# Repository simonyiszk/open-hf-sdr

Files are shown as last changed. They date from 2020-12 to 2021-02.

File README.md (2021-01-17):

Open HF SDR
===========

# Specs
* 0.5-30 MHz input freq range

# Receiver
## First stage
* 30 MHz low-pass filter
* Programmable auttenator with 10, 20, and 30 dB options
* Highly linear mixer to 37.224 MHz IF

## Second stage
* IF filter for 37.224 MHz
* IF amplifier
* Mixer to 9 MHz IF

## Third stage
* IF filter for 9 MHz IF with 0.5 MHz bandwidth
* Diff amp to ADC

## Fourth stage
* ADC with 8 MSps, undersampling the 9 MHz IF to 1 MHz

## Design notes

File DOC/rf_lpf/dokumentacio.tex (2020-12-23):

\begin{center}
	\Huge
	30\,MHz vágású aluláteresztő szűrő RH-SDR-hez
	
	\Large
	HA5KFU projekt
	
	\Large
	Keresztes Botond
\end{center}

\section*{Specifikáció}

Cél egy olyan $50\,\Omega$ be-, és kimenetű $30\,MHz$ vágású aluláteresztő szűrő tervezése, mely $44\,MHz$ frekvencián már legalább $40\,dB$-es elnyomást biztosít. Ez azért szükséges, hogy a későbbi keverésből adódó tükörfrekvenciákat megbízhatóan el lehessen nyomni. Továbbá követelmény, hogy a szűrő legfeljebb hetedfokú legyen, ez a főmérnök (Kiss Ádám) által szabott határ.

\section*{Első iteráció}

A szűrő méretezéséhez az \url{https://rf-tools.com/lc-filter/} linken található programot használtam, itt specifikálni lehet a szűrő típusát (Csebisev, Butterworth stb.), jellegét (alul-, felüláteresztő stb.), vágási frekvenciá(ka)t, illetve ahol releváns, egyéb paramétereket (pl. áteresztő sávi hullámosság). Ezen kívül kiszámíttathatók az elemek pontos értékei, vagy a szabványos sorokban található értékekből felépített közelítése.

Az első próbálkozás (\ref{fig:csebisev_390n}-es ábra) egy hetedfokú Csebisev szűrő volt, ugyanis ez ígérkezett megfelelő meredekséget adni a határok megtartásához. Ezt teljesítette is, bár csak úgy, ha $0,3\,dB$-nyi hullámosságot engedélyeztem a zárósávban. Ez a struktúra két különböző kondenzátor, illetve induktivitás értéket ($360\,nH$, $390\,nH$) tartalmazott. A számok relatív közelsége miatt adta magát, hogy áttérjek egyfajta tekercsértékre (\ref{fig:csebisev_360n}-es ábra), így csökkentve a különböző alkatrészek mennyiségét.

Az \texttt{rf-tools} tervezőben sajnos nincs lehetőség egyes értékek manuális átírására, így a további szimulációkat LTSpice-ban végeztem\footnotemark. Ennek az az előnye, hogy exportálhatók a szimulációs eredmények. Ezzel a lehetőséggel éltem is, és Octave segítségével ábrázoltam az eredményeket (lásd: Függelék).
\footnotetext{A forrás és terhelés ellenállás osztása miatt itt a kimenet alapból $-6\,dB$ csillapítással számítódik, ezt az ábrázolásnál ki kell (lehet) kompenzálni.}

Az tekercsek egységes $360\,nH$-re cserélése ugyan kicsit kijjebb tolja a $-3\,dB$-es pontot, viszont növeli az áteresztő sávi hullámosságot, és csökkenti az elnyomás mértékét $44\,MHz$-en. Mérlegelendő, hogy az alkatrészek számán szeretnénk-e spórolni, vagy inkább egy jobb karakterisztikájú szűrőre van szükségünk.

Erre a diskurzusra viszont sor sem kerülhetett, ugyanis ezen szűrők úgy lettek méretezve, hogy az \texttt{rf-tools} az E24-es sorban található szabványos értékeket használta fel a tervezéshez, viszont hamar kiderült, hogy ezen alkatrészek elérhetősége (névelegesen a $360\,nH$-s tekercsé) igencsak csekély.

\newpage

\section*{Második iteráció}

Világossá vált, hogy ha bármiféle választékot szeretnénk az alkatrészek beszerzésekor, akkor át kell térni E12-es értéksorra. Ebben természetesen \enquote{szellősebben} találhatók elemértékek, viszont az elérhetőségük jóval jobb.

Ádámmal konzultálva arra jutottunk, hogy a prioritás a $44\,MHz$-es elnyomási kritérium teljesítése, és hogy ez akár kierőszakolható a törésponti frekvenciának a csökkentésével. A határértékekkel való kis játék után adódott, hogy a sávszélesség $29,5\,MHz$-re választásával elérhető a specifikált elnyomás, mindössze $0,2\,dB$ hullámossággal -- az \texttt{rf-tools} ez számította, a szimuláció (\ref{fig:csebisev_295}-as ábra) ezzel nem teljesen egyezett.

Ez egy észszerű kompromisszumnak mutatkozik az eredeti követelmények és az alkatrész elérhetőség között, így ezt a változatot szándékozzuk használni.

\section*{Alkatrészek}

Alkatrészek keresésekor fő szempont volt az ár és az elérhetőség és természetesen a minőség. Ez a tekercs esetén magas rezonanciafrekvenciát és alacsony ellenállást jelent, kondenzátoroknál pedig igyekeztem olyan márkából is beválogatni egyet-egyet, melyekről mondták nekem, hogy azok jó minőségűek nagyobb frekvenciákon is. Jelenleg úgy alakult, hogy ez minden esetben a Kemet, de ilyen még pl. a Vishay vagy a Murata is.

Kiválasztásra került több lehetséges érték, ha esetleg gondok merülnének fel a rendeléssel (értsd: elfogy a raktárkészlet), illetve a kondenzátoroknál két különböző méretből is listáztam terméket, ugyanis itt nem elhanyagolható az árbeli különbség. Az általam javasolt alkatrészek minden táblázatban és a hivatkozások között is vastagon ki vannak emelve, de alkalmazásuk akár vita tárgyát képezheti.

\subsection*{Tekercs}

\begin{center}
	\begin{tabular}{ c c c c c c c c }
		\textbf{Forgalmazó} & \textbf{Gyártó} & \textbf{Érték} & \textbf{Méret} & \textbf{Ellenállás} & \textbf{SRF} & \textbf{Ár [db]} & \textbf{Link}\\
		
		\hline \\
		
		\textbf{Farnell} & \textbf{TDK} & \textbf{390\,nH} & \textbf{1210} & \textbf{0,45\,$\Omega$} & \textbf{250\,MHz} & \textbf{kb. 60\,Ft} & \textbf{\cite{tdk_tekercs}} \\[10pt]
		
		Farnell & WE & 390\,nH & 0603 & 2,3\,$\Omega$ & 350\,MHz & kb. 30\,Ft & \cite{we_tekercs} \\[10pt]
		
		Lomex & KOA & 390\,nH & 1210 & 0,45\,$\Omega$ & 250\,MHz & kb. 45\,Ft & \cite{koa_tekercs}

	 	\end{tabular}
\end{center}

\subsection*{Kondenzátor}

\begin{center}
	\begin{tabular}{ c c c c c c c c }
		\textbf{Forgalmazó} & \textbf{Gyártó} & \textbf{Érték} & \textbf{Méret} & \textbf{Tűrés} & \textbf{Egyéb} & \textbf{Ár [db]} & \textbf{Link}\\
		
		\hline \\
		
		\textbf{Farnell} & \textbf{Kemet} & \textbf{150\,pF} & \textbf{0805} & \textbf{5\%} & \textbf{NP0} & k\textbf{b. 20\,Ft} & \textbf{\cite{kemet_150p_0805}} \\[10pt]
		
		Farnell & WE & 150\,pF & 0805 & 10\% & X7R & kb. 20\,Ft & \cite{we_150p_0805} \\[10pt]
		
		Farnell & Walsin & 150\,pF & 0603 & 5\% & NP0 & kb. 6\,Ft & \cite{walsin_150p_0603} \\[10pt]
		
		Farnell & Kemet & 150\,pF & 0603 & 5\% & NP0 & kb. 9\,Ft & \cite{kemet_150p_0603} \\[10pt]
		
		\hline \\
		
		\textbf{Farnell} & \textbf{Kemet} & \textbf{270\,pF} & \textbf{0805} & \textbf{5\%} & \textbf{NP0} & \textbf{kb. 21\,Ft} & \textbf{\cite{kemet_270p_0805}} \\[10pt]
		
		Farnell & Multicomp & 270\,pF & 0805 & 5\% & NP0 & kb. 23\,Ft & \cite{multicomp_270p_0805} \\[10pt]
		
		Farnell & Walsin & 270\,pF & 0603 & 10\% & X7R & kb. 7\,Ft & \cite{walsin_270p_0603} \\[10pt]
		
		Farnell & Kemet & 270\,pF & 0603 & 5\% & NP0 & kb. 15\,Ft & \cite{kemet_270p_0603} \\[10pt]
		
	\end{tabular}
\end{center}

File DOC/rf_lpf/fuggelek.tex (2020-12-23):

\section*{Függelék}
\label{sec:fuggelek}

\begin{thebibliography}{1}
	
	\bibitem{tdk_tekercs} \textbf{TDK tekercs 390\,nH} \url{https://hu.farnell.com/tdk/nlv32t-r39j-ef/inductor-0-39uh-0-45a-1210/dp/2747947}
	
	\bibitem{we_tekercs} Würth Elektronik tekercs 390\,nH \url{https://hu.farnell.com/wurth-elektronik/7447860239/inductor-390nh-350mhz-0-15a-0603/dp/3518544RL}
	
	\bibitem{koa_tekercs} KOA tekercs 390\,nH \url{https://lomex.hu/hu/webshop/#/search,93-00-46/stype,1}
	
	\bibitem{kemet_150p_0805} \textbf{Kemet kondenzátor 150\,pF, 0805} \url{https://hu.farnell.com/kemet/c0805c151j5gacauto/cap-150pf-50v-5-c0g-np0-0805/dp/2905219}
	
	\bibitem{we_150p_0805} Würth Elektronik kondenzátor 150\,pF, 0805 \url{https://hu.farnell.com/wurth-elektronik/885012207055/cap-150pf-25v-10-x7r-0805/dp/2812410}
	
	\bibitem{walsin_150p_0603} Walsin kondenzátor 150\,pF, 0603 \url{https://hu.farnell.com/walsin/0603n151j500ct/cap-150pf-50v-5-c0g-np0-0603/dp/2496888}
	
	\bibitem{kemet_150p_0603} Kemet kondenzátor 150\,pF, 0603 \url{https://hu.farnell.com/kemet/c0603c151j5gactu/cap-150pf-50v-5-c0g-np0-0603/dp/1414615}
	
	\bibitem{kemet_270p_0805} \textbf{Kemet kondenzátor 270\,pF, 0805} \url{https://hu.farnell.com/kemet/c0805c271j5gactu/cap-270pf-50v-5-c0g-np0-0805/dp/1414684}
	
	\bibitem{multicomp_270p_0805} Multicomp Pro kondenzátor 270\,pF, 0805 \url{https://hu.farnell.com/multicomp/mc0805n271j500ct/cap-270pf-50v-5-c0g-np0-0805/dp/1759211}
	
	\bibitem{walsin_270p_0603} Walsin kondenzátor 270\,pF, 0603 \url{https://hu.farnell.com/walsin/0603b271k500ct/cap-270pf-50v-10-x7r-0603-reel/dp/2524832}
	
	\bibitem{kemet_270p_0603} Kemet kondenzátor 270\,pF, 0603 \url{https://hu.farnell.com/kemet/c0603c271j5gactu/cap-270pf-50v-5-c0g-np0-0603/dp/1414629}

\end{thebibliography}

\newpage

\subsection*{7-ed fokú Csebisev szűrő, 390nH induktivitással (E24-es sor)}

\begin{figure}[!ht]
	\centering
	\begin{subfigure}[b]{\textwidth}
		\centering
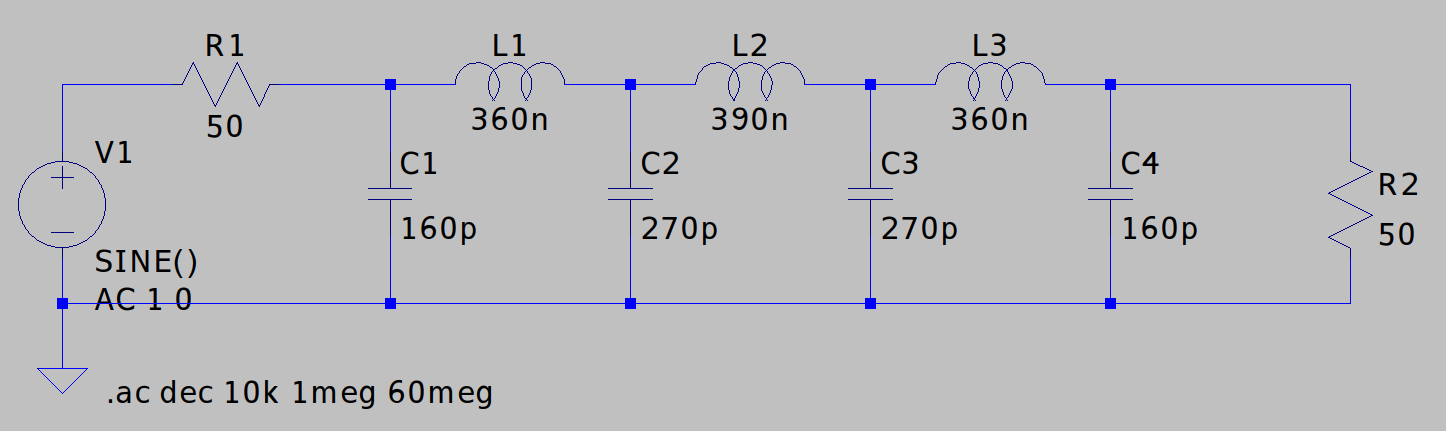
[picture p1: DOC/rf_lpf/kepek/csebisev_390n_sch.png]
		\centerline{[}
		\label{fig:csebisev_390n_sch}
		\caption{Struktúra}
	\end{subfigure}
	\hfill
	\begin{subfigure}[b]{\textwidth}
		\centering
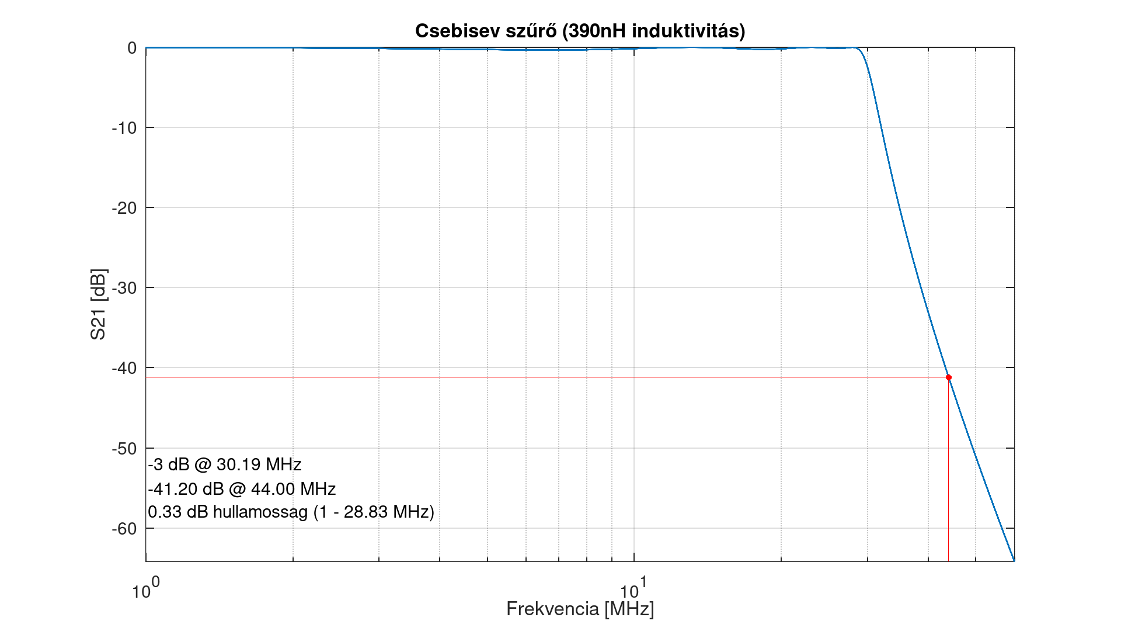
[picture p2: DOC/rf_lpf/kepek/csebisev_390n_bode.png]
		\centerline{[}
		\label{fig:csebisev_390n_bode}
		\caption{Frekvenciamenet}
	\end{subfigure}
	\caption{7-ed fokú Csebisev szűrő, 390nH induktivitással (E24-es sor)}
	\label{fig:csebisev_390n}
\end{figure}

\newpage

\subsection*{7-ed fokú Csebisev szűrő, kizárólag 360nH induktivitásokkal (E24-es sor)}

\begin{figure}[!ht]
	\centering
	\begin{subfigure}[b]{\textwidth}
		\centering
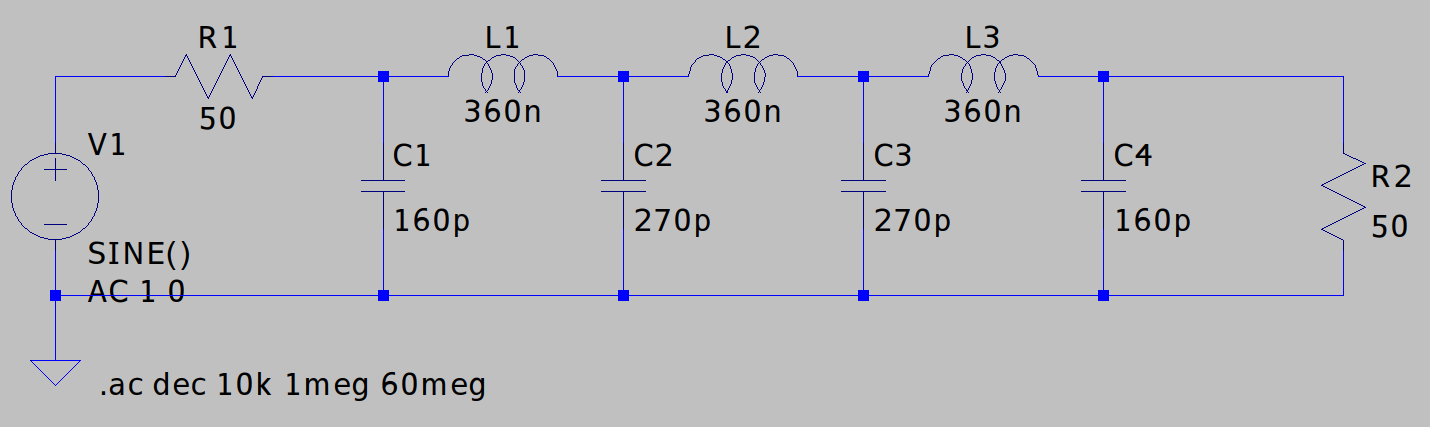
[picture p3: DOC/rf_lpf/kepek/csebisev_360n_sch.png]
		\centerline{[}
		\label{fig:csebisev_360n_sch}
		\caption{Struktúra}
	\end{subfigure}
	\hfill
	\begin{subfigure}[b]{\textwidth}
		\centering
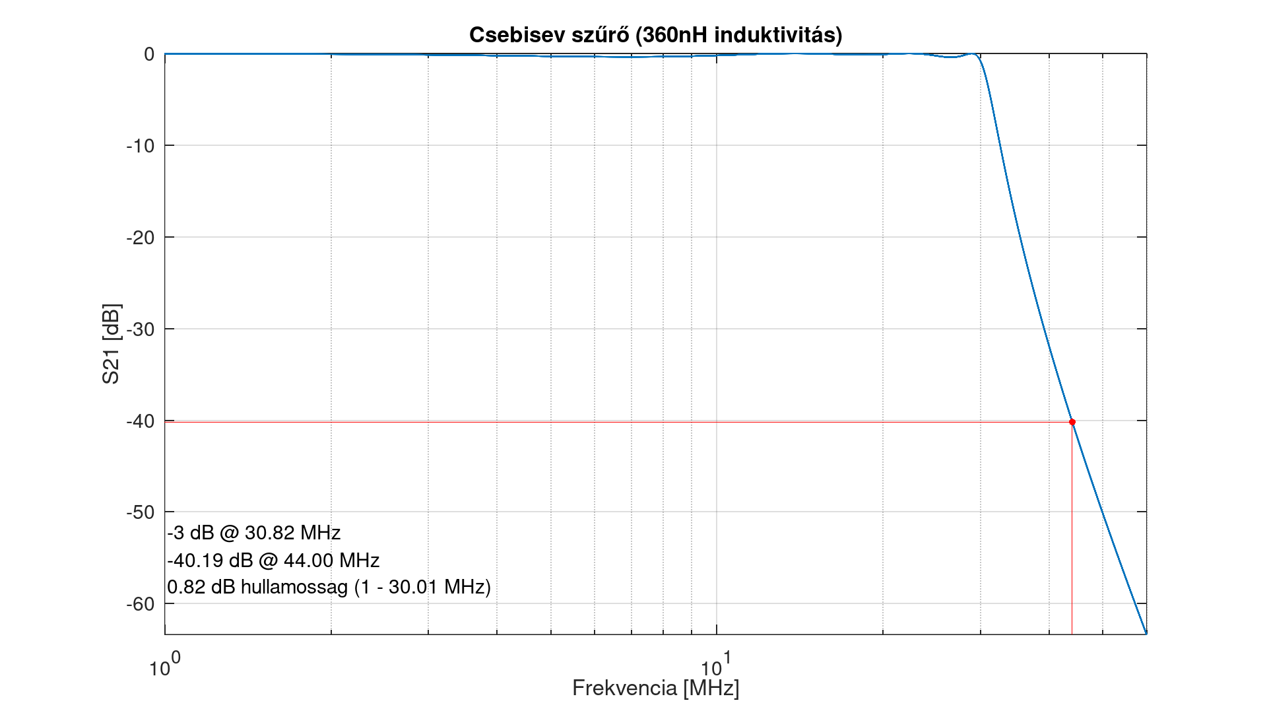
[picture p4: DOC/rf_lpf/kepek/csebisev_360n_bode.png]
		\centerline{[}
		\label{fig:csebisev_360n_bode}
		\caption{Frekvenciamenet}
	\end{subfigure}
	\caption{7-ed fokú Csebisev szűrő, kizárólag 360nH induktivitásokkal (E24-es sor)}
	\label{fig:csebisev_360n}
\end{figure}

\newpage

\subsection*{7-ed fokú Csebisev szűrő, 29,5\,MHz vágással és E12-es sorelemekkel}

\begin{figure}[!ht]
	\centering
	\begin{subfigure}[b]{\textwidth}
		\centering
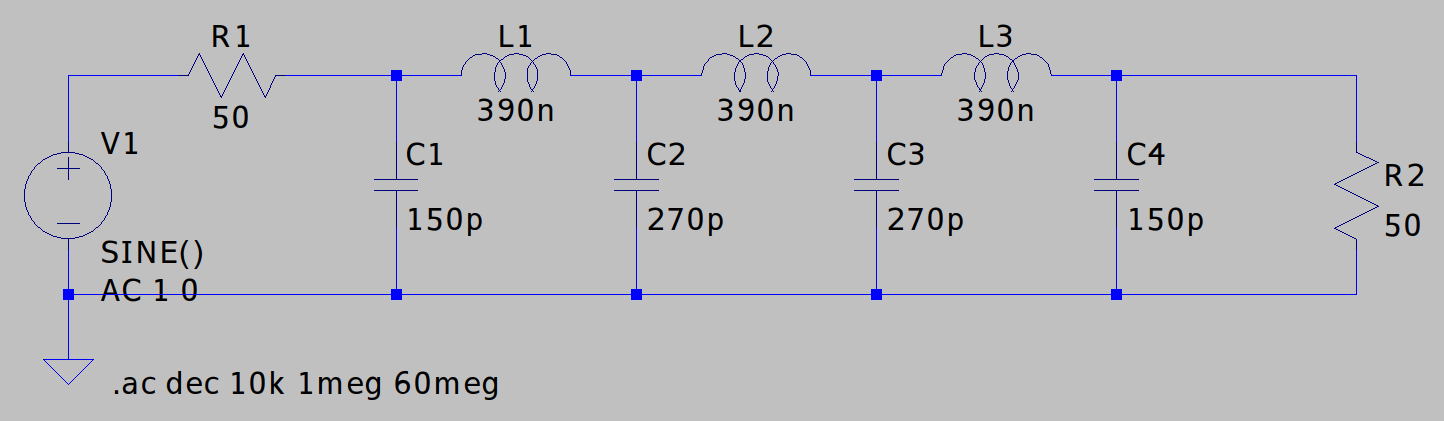
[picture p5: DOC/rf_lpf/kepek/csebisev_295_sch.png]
		\centerline{[}
		\label{fig:csebisev_295_sch}
		\caption{Struktúra}
	\end{subfigure}
	\hfill
	\begin{subfigure}[b]{\textwidth}
		\centering
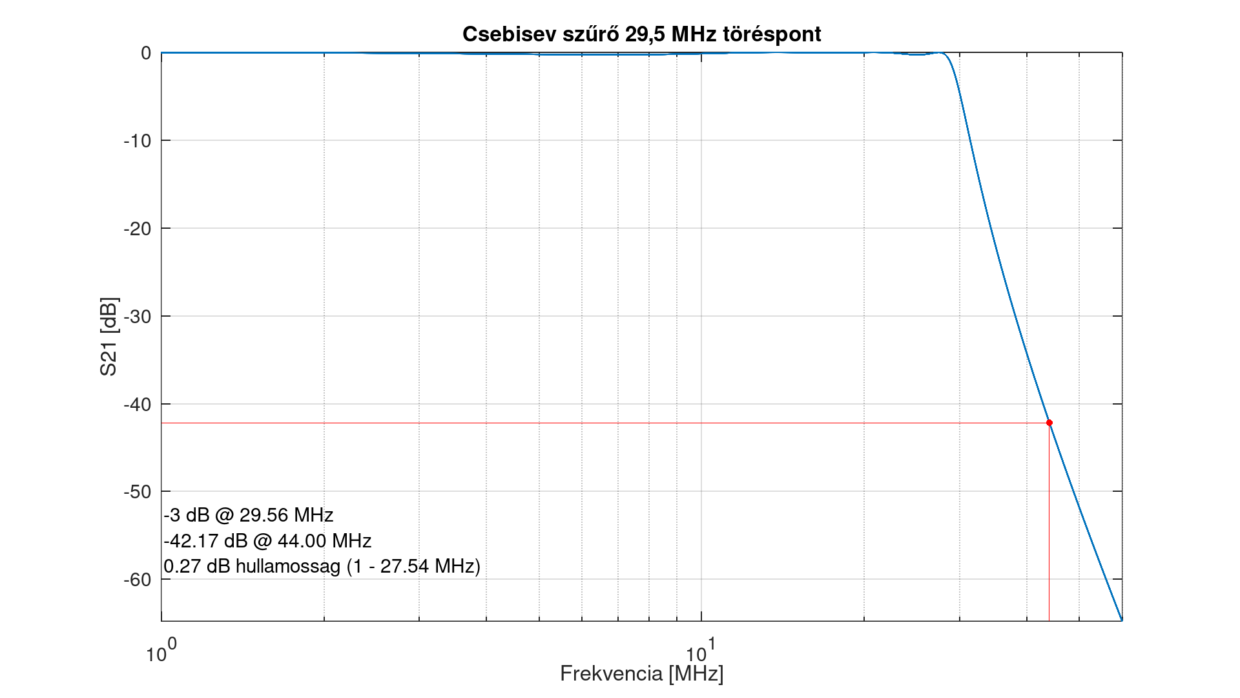
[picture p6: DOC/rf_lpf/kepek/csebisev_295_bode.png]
		\centerline{[}
		\label{fig:csebisev_295_bode}
		\caption{Frekvenciamenet}
	\end{subfigure}
	\caption{7-ed fokú Csebisev szűrő, 29,5\,MHz vágással és E12-es sorelemekkel}
	\label{fig:csebisev_295}
\end{figure}

\newpage

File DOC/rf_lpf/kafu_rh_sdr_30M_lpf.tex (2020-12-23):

\documentclass[12pt,a4paper,oneside]{article}
\usepackage{geometry}
	\geometry                  %margók és lapméret beállítása
		{
			a4paper,
			top=20mm,
			bottom=25mm,
			left=25mm,
			right=25mm
		}
	\pagestyle{plain}           %fejléc üres, lábléc az oldalszámot tartalmazza
\usepackage{setspace}           %sorközt lehet beállítani
	\singlespacing              %egyszeres sorköz
\usepackage{indentfirst}        %bekezdések formázása
	\setlength{\parindent}{1em} %bekezdés első sorának behúzása
	\setlength{\parskip}{6pt}   %bekezdések közötti távolság
\usepackage[autostyle]{csquotes}%idézőjelek helyes formázásához
	
\usepackage[utf8]{inputenc}     %karakterkódolás
\usepackage[magyar]{babel}      %helyesírás-ellenőrzés
\usepackage[T1]{fontenc}        %szimbólumkódolás

\usepackage{amsmath}            %matematikai képletekhez
\usepackage{amssymb}            %több matematikai jelölés (automatikusan betölti az 'amsfonts' csomagot)
\usepackage{graphicx}           %képek beillesztéséhez (valószínűleg betölti a 'graphics' csomagot, de nem találtam erre egyértelmű hivatkozást)
	\graphicspath               %képek elérési útvonala, szabadon bővíthető/csökkenthető
	{
		{./}
		{./elolap/}
		{./kepek/}
	}
\usepackage{enumitem}           %felsorolásokat lehet vele formázni
\usepackage{titling}            %title, author, stb. definiálásához, használatához
\usepackage{hyperref}           %a hivatkozásokat kezeli
	\hypersetup                 %a hivatkozásokat lehet formálni
	{
		colorlinks=true,        %linkek színezésének engedélyezése
		citecolor=black,        %dokumentumon belüli hivatkozás színe
		linkcolor=red,          %valami másféle dokumentumon belüli hivatkozás színe
		urlcolor=blue,          %weblaphivatkozások színe
	}
\usepackage[center]{caption}    %képaláírásokat alapból középre igazítja
\usepackage{subcaption}         %subfigure környezethez
\usepackage{float}              %'lebegő' objektumok (pl. képek, táblázatok) pozícionálására

\begin{document}
	\include{dokumentacio}
	\include{fuggelek}
\end{document}

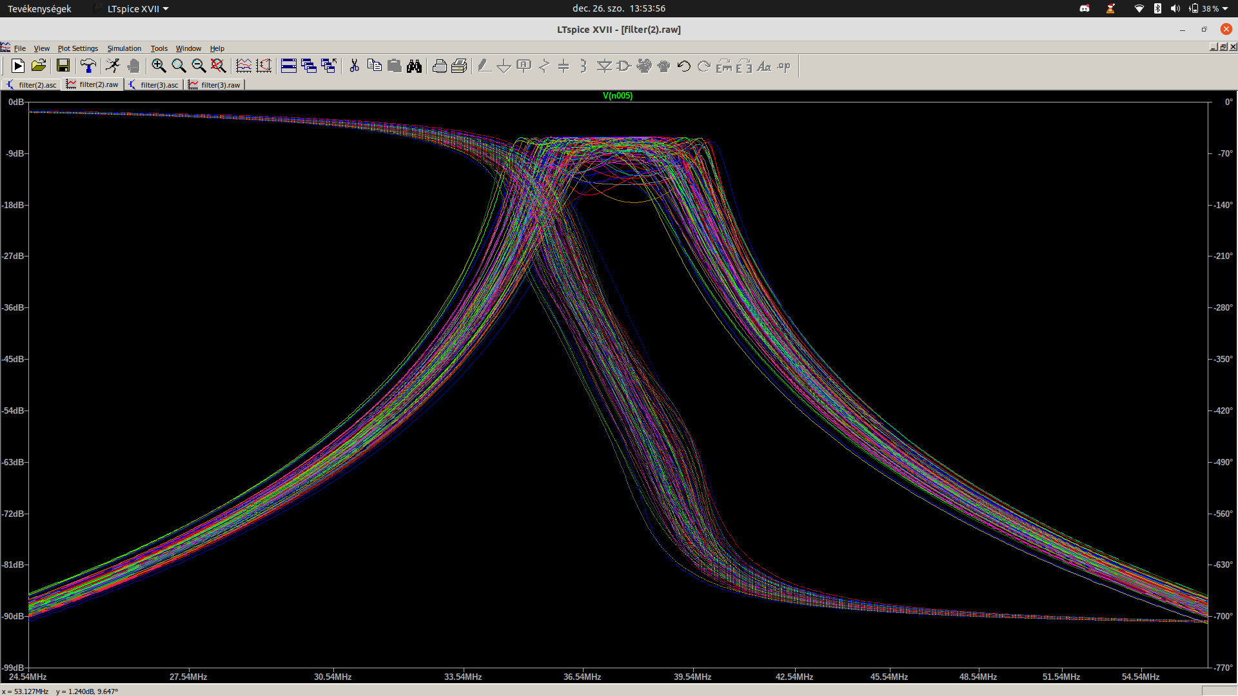
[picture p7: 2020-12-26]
DOC/rf_KF_BPF/ripple.png

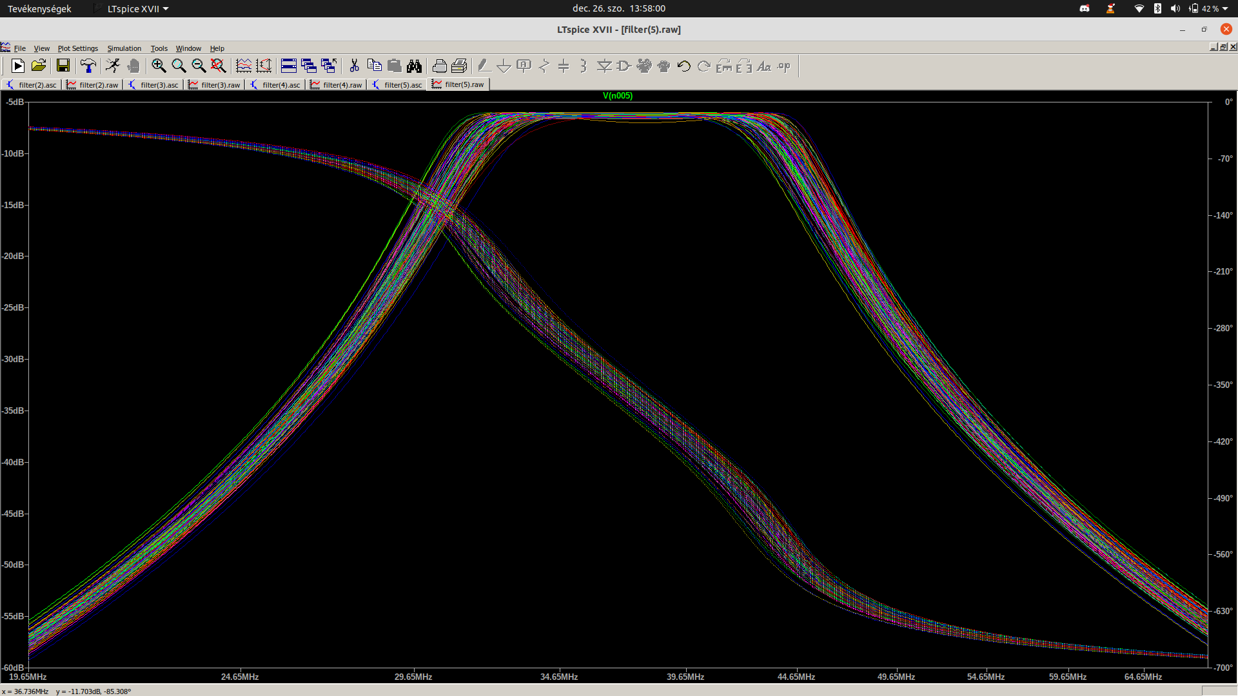
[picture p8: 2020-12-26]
DOC/rf_KF_BPF/final.png

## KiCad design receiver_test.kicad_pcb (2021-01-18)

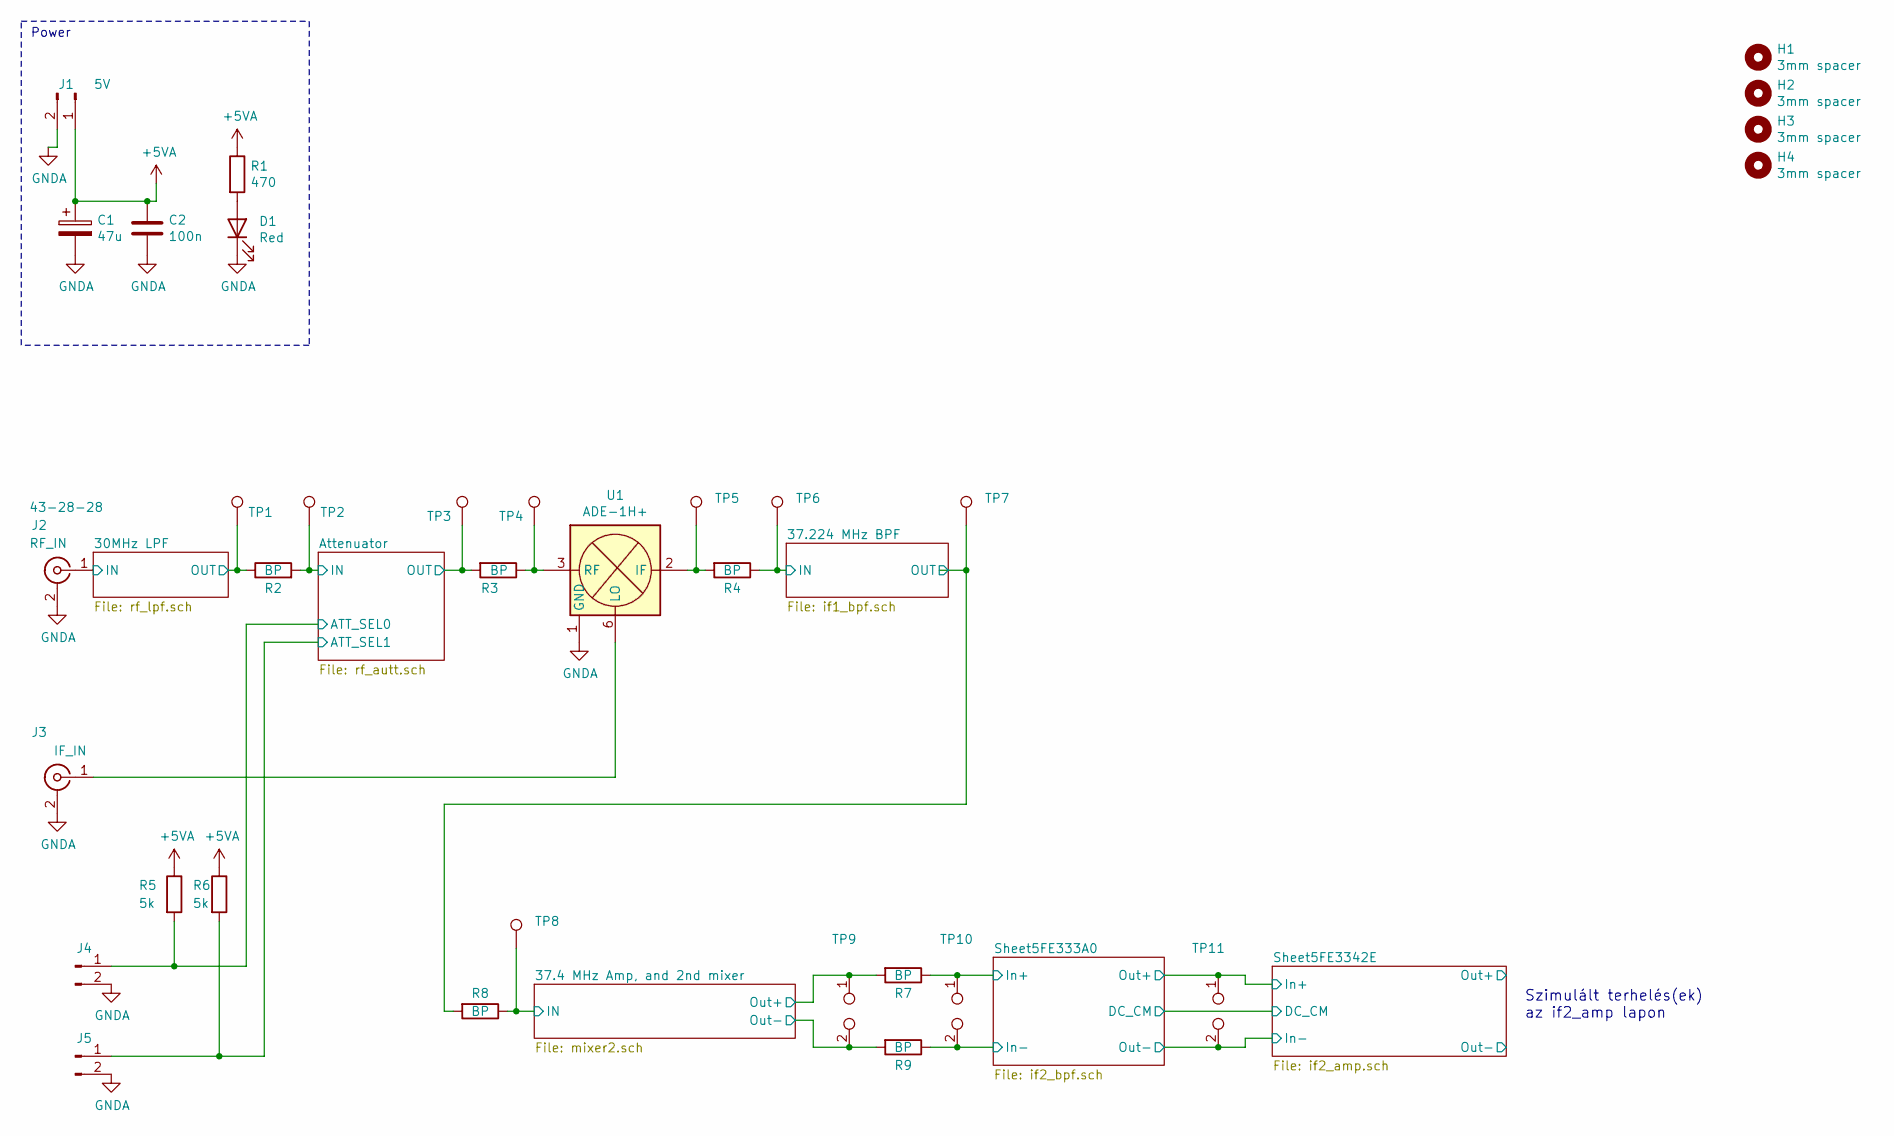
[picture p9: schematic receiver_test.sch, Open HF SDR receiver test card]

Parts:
C1: 47u; CP_Elec_6.3x5.3
C2: 100n; C_0805_2012Metric_Pad1.15x1.40mm_HandSolder
D1: Red; LED_0805_2012Metric_Pad1.15x1.40mm_HandSolder
H1, H2, H3, H4: 3mm spacer; MountingHole_3.2mm_M3
J1: 5V; PinSocket_1x02_P2.54mm_Vertical
J2: RF_IN; SMA_Molex_73251-1153_EdgeMount_Horizontal
J3: IF_IN; SMA_Molex_73251-1153_EdgeMount_Horizontal
J4, J5: Conn_01x02_Male; PinSocket_1x02_P2.54mm_Vertical
R1: 470; R_0805_2012Metric_Pad1.15x1.40mm_HandSolder
R2, R3, R4, R7, R8, R9: BP; R_1206_3216Metric_Pad1.42x1.75mm_HandSolder
R5, R6: 5k; R_0805_2012Metric_Pad1.15x1.40mm_HandSolder
TP1, TP2, TP3, TP4, TP5, TP6, TP7, TP8: TestPoint; PinHeader_1x01_P2.54mm_Vertical
TP9, TP10, TP11: TestPoint_2Pole; PinHeader_1x02_P2.54mm_Vertical
U1: ADE-1H+; Mini-Circuits_CD542_LandPatternPL-052

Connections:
+5VA: C1.1, C2.1, J1.1, R1.1, R5.1, R6.1; also elsewhere on the board
/30MHz LPF/IN: J2.1 (In); also elsewhere on the board
/30MHz LPF/OUT: R2.1, TP1.1; also elsewhere on the board
/37.4 MHz Amp, and 2nd mixer/IN: R8.1, TP8.1; also elsewhere on the board
/37.4 MHz Amp, and 2nd mixer/Out+: R7.2, TP9.1; also elsewhere on the board
/37.4 MHz Amp, and 2nd mixer/Out-: R9.2, TP9.2; also elsewhere on the board
/37.224 MHz BPF/IN: R4.1, TP6.1; also elsewhere on the board
/Attenuator/ATT_SEL0: J4.1, R5.2; also elsewhere on the board
/Attenuator/ATT_SEL1: J5.1, R6.2; also elsewhere on the board
/Attenuator/IN: R2.2, TP2.1; also elsewhere on the board
/Attenuator/OUT: R3.2, TP3.1; also elsewhere on the board
/Sheet5FE333A0/In+: R7.1, TP10.1; also elsewhere on the board
/Sheet5FE333A0/In-: R9.1, TP10.2; also elsewhere on the board
/Sheet5FE3342E/In+: TP11.1; also elsewhere on the board
/Sheet5FE3342E/In-: TP11.2; also elsewhere on the board
GNDA: C1.2, C2.2, D1.1 (K), J1.2, J2.2 (Ext), J3.2 (Ext), J4.2, J5.2, U1.1 (GND), U1.4 (GND), U1.5 (GND); also elsewhere on the board
unnamed: D1.2 (A), R1.2
unnamed: J3.1 (In), U1.6 (LO)
unnamed: R3.1, TP4.1, U1.3 (RF)
unnamed: R4.2, TP5.1, U1.2 (IF)
unnamed: R8.2, TP7.1

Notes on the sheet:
Power
Szimulált terhelés(ek) az if2_amp lapon

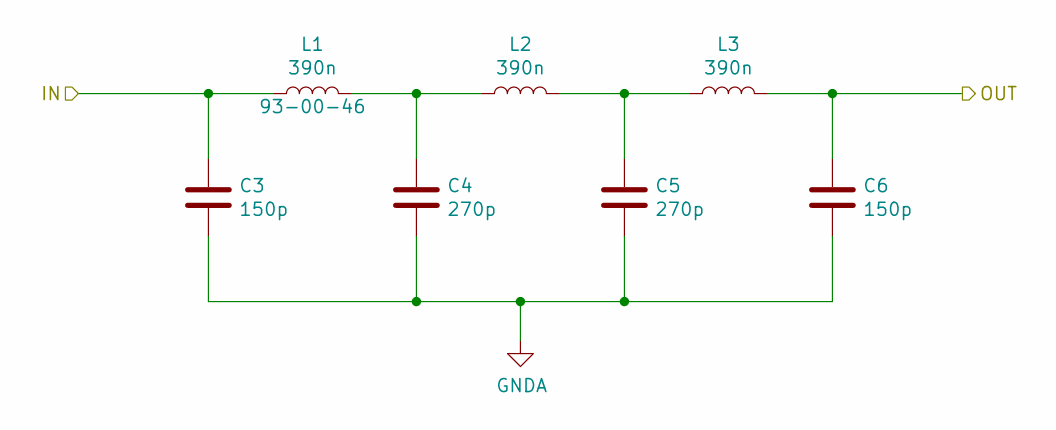
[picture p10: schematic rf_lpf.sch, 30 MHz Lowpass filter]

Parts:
C3, C6: 150p; C_0805_2012Metric_Pad1.15x1.40mm_HandSolder
C4, C5: 270p; C_0805_2012Metric_Pad1.15x1.40mm_HandSolder
L1, L2, L3: 390n; L_1206_3216Metric_Pad1.42x1.75mm_HandSolder

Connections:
/30MHz LPF/IN: C3.1, L1.1; also elsewhere on the board
/30MHz LPF/OUT: C6.1, L3.2; also elsewhere on the board
GNDA: C3.2, C4.2, C5.2, C6.2; also elsewhere on the board
unnamed: C4.1, L1.2, L2.1
unnamed: C5.1, L2.2, L3.1

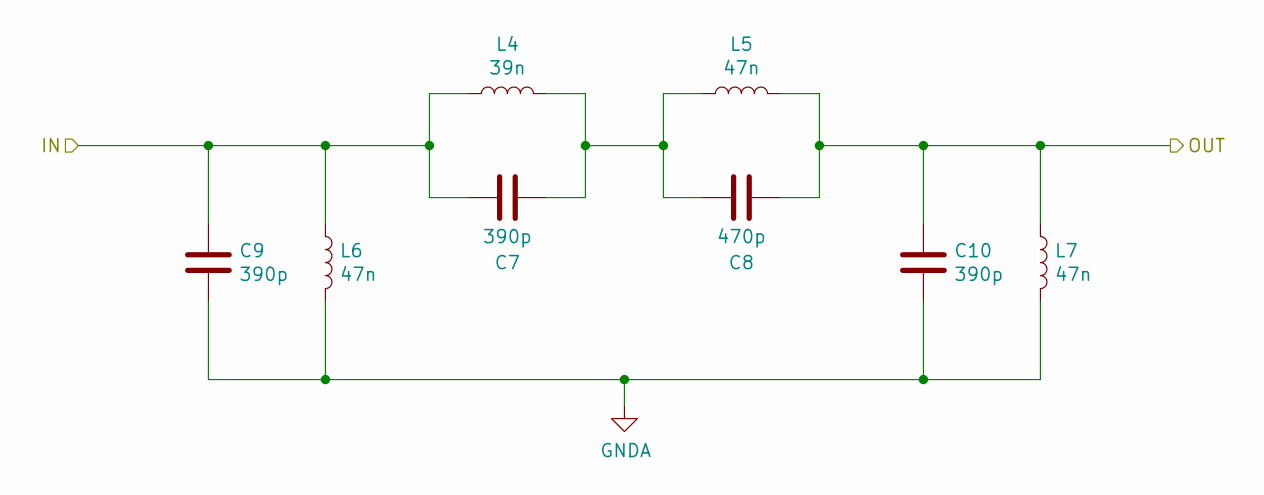
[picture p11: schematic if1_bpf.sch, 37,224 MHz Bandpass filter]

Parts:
C7, C9, C10: 390p; C_0805_2012Metric_Pad1.15x1.40mm_HandSolder
C8: 470p; C_0805_2012Metric_Pad1.15x1.40mm_HandSolder
L4: 39n; L_0402_1005Metric_Pad0.77x0.64mm_HandSolder; Farnell 2846682RL
L5, L6, L7: 47n; L_0603_1608Metric_Pad1.05x0.95mm_HandSolder

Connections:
/37.224 MHz BPF/IN: C7.1, C9.1, L4.1, L6.1; also elsewhere on the board
/37.224 MHz BPF/OUT: C8.2, C10.1, L5.2, L7.1
GNDA: C9.2, C10.2, L6.2, L7.2; also elsewhere on the board
unnamed: C7.2, C8.1, L4.2, L5.1

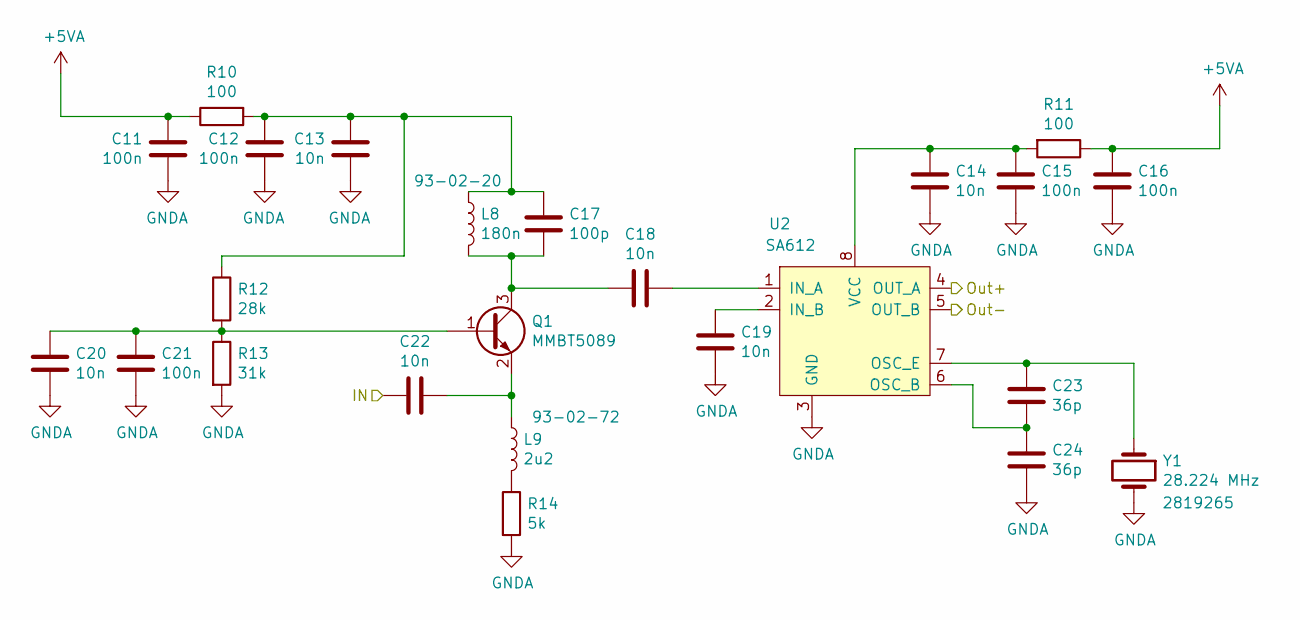
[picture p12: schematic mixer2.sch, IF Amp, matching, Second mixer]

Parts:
C11, C12, C15, C16, C21: 100n; C_0805_2012Metric_Pad1.15x1.40mm_HandSolder
C13, C14, C18, C19, C20, C22: 10n; C_0805_2012Metric_Pad1.15x1.40mm_HandSolder
C17: 100p; C_0805_2012Metric_Pad1.15x1.40mm_HandSolder
C23, C24: 36p; C_0805_2012Metric_Pad1.15x1.40mm_HandSolder
L8: 180n; L_1210_3225Metric_Pad1.42x2.65mm_HandSolder
L9: 2u2; L_0805_2012Metric_Pad1.15x1.40mm_HandSolder
Q1: MMBT5089; SOT-23
R10, R11: 100; R_0805_2012Metric_Pad1.15x1.40mm_HandSolder
R12: 28k; R_0805_2012Metric_Pad1.15x1.40mm_HandSolder
R13: 31k; R_0805_2012Metric_Pad1.15x1.40mm_HandSolder
R14: 5k; R_0805_2012Metric_Pad1.15x1.40mm_HandSolder
U2: SA612; SO-8_3.9x4.9mm_P1.27mm
Y1: 28.224 MHz; Crystal_HC49-U_Vertical; Farnell 2819265

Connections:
+5VA: C11.1, C16.1, R10.1, R11.1; also elsewhere on the board
/37.4 MHz Amp, and 2nd mixer/IN: C22.1; also elsewhere on the board
/37.4 MHz Amp, and 2nd mixer/Out+: U2.4 (OUT_A); also elsewhere on the board
/37.4 MHz Amp, and 2nd mixer/Out-: U2.5 (OUT_B); also elsewhere on the board
GNDA: C11.2, C12.2, C13.2, C14.2, C15.2, C16.2, C19.2, C20.2, C21.2, C24.2, R13.2, R14.2, U2.3 (GND), Y1.2; also elsewhere on the board
unnamed: C12.1, C13.1, C17.1, L8.1, R10.2, R12.1
unnamed: C14.1, C15.1, R11.2, U2.8 (VCC)
unnamed: C17.2, C18.2, L8.2, Q1.3 (C)
unnamed: C18.1, U2.1 (IN_A)
unnamed: C19.1, U2.2 (IN_B)
unnamed: C20.1, C21.1, Q1.1 (B), R12.2, R13.1
unnamed: C22.2, L9.1, Q1.2 (E)
unnamed: C23.1, U2.7 (OSC_E), Y1.1
unnamed: C23.2, C24.1, U2.6 (OSC_B)
unnamed: L9.2, R14.1

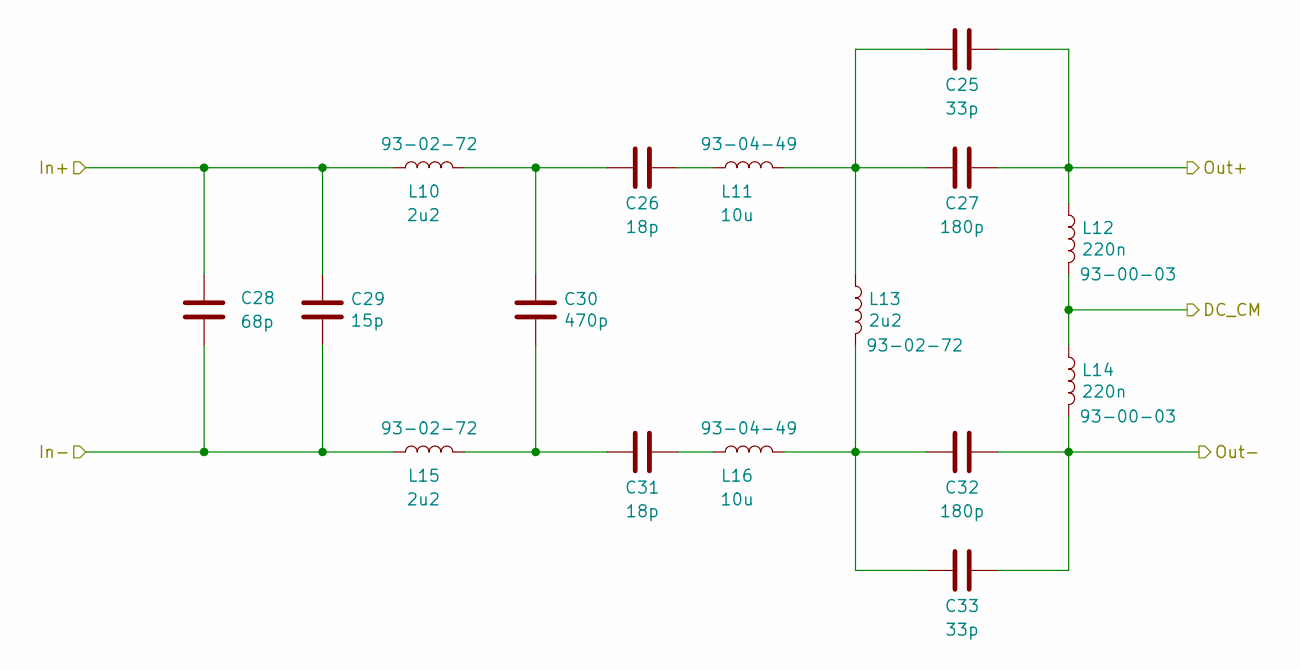
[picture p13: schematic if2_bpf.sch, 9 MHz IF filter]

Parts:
C25, C33: 33p; C_0805_2012Metric_Pad1.15x1.40mm_HandSolder
C26, C31: 18p; C_0805_2012Metric_Pad1.15x1.40mm_HandSolder
C27, C32: 180p; C_0805_2012Metric_Pad1.15x1.40mm_HandSolder
C28: 68p; C_0805_2012Metric_Pad1.15x1.40mm_HandSolder
C29: 15p; C_0805_2012Metric_Pad1.15x1.40mm_HandSolder
C30: 470p; C_0805_2012Metric_Pad1.15x1.40mm_HandSolder
L10, L13, L15: 2u2; L_0805_2012Metric_Pad1.15x1.40mm_HandSolder
L11, L16: 10u; L_1210_3225Metric_Pad1.42x2.65mm_HandSolder
L12, L14: 220n; L_1210_3225Metric_Pad1.42x2.65mm_HandSolder

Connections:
/Sheet5FE333A0/DC_CM: L12.2, L14.1; also elsewhere on the board
/Sheet5FE333A0/In+: C28.1, C29.1, L10.1; also elsewhere on the board
/Sheet5FE333A0/In-: C28.2, C29.2, L15.1; also elsewhere on the board
/Sheet5FE3342E/In+: C25.1, C27.1, L12.1; also elsewhere on the board
/Sheet5FE3342E/In-: C32.2, C33.2, L14.2; also elsewhere on the board
unnamed: C25.2, C27.2, L11.2, L13.1
unnamed: C26.1, L11.1
unnamed: C26.2, C30.1, L10.2
unnamed: C30.2, C31.2, L15.2
unnamed: C31.1, L16.1
unnamed: C32.1, C33.1, L13.2, L16.2

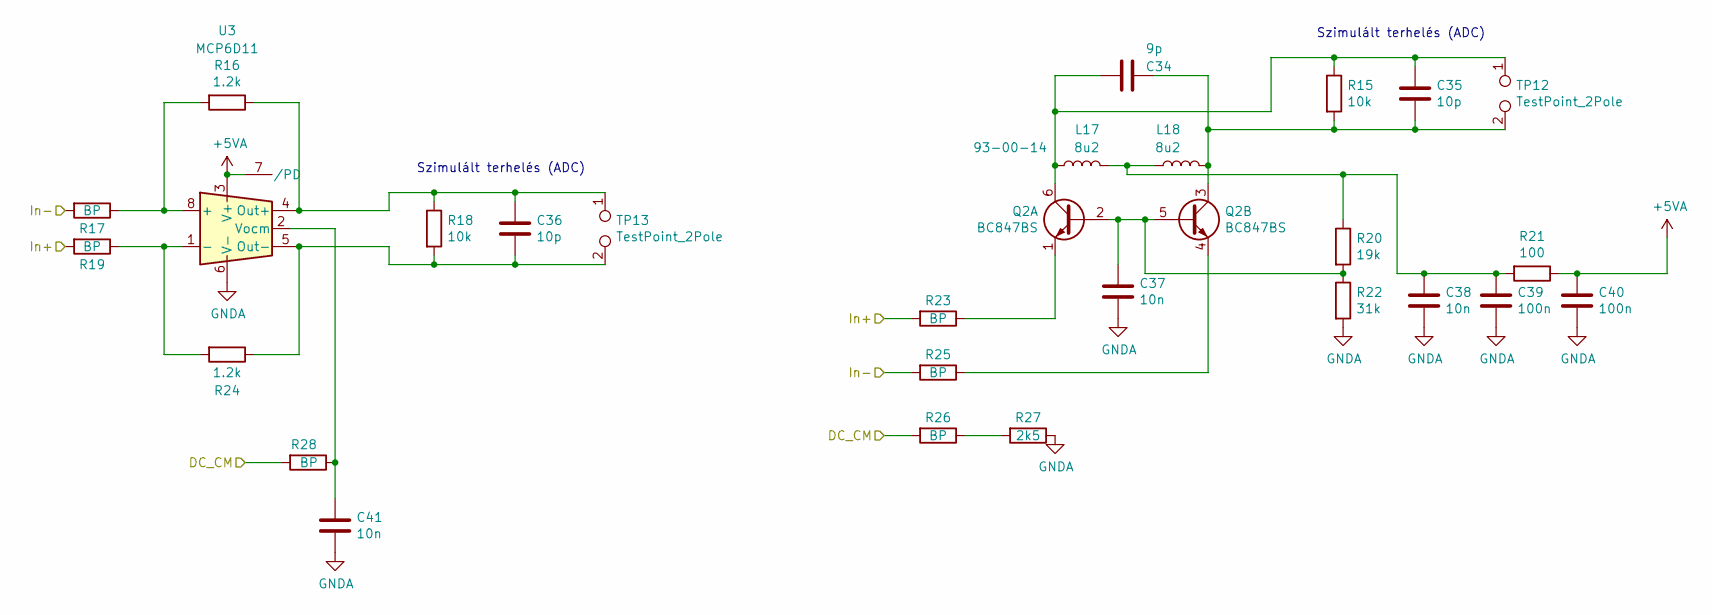
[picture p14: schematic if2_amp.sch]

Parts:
C34: 9p; C_0805_2012Metric_Pad1.15x1.40mm_HandSolder
C35, C36: 10p; C_0805_2012Metric_Pad1.15x1.40mm_HandSolder
C37, C38, C41: 10n; C_0805_2012Metric_Pad1.15x1.40mm_HandSolder
C39, C40: 100n; C_0805_2012Metric_Pad1.15x1.40mm_HandSolder
L17, L18: 8u2; L_1210_3225Metric_Pad1.42x2.65mm_HandSolder
Q2: BC847BS; SOT-363_SC-70-6
R15, R18: 10k; R_0805_2012Metric_Pad1.15x1.40mm_HandSolder
R16, R24: 1.2k; R_0805_2012Metric_Pad1.15x1.40mm_HandSolder
R17, R19, R23, R25, R26, R28: BP; R_1206_3216Metric_Pad1.42x1.75mm_HandSolder
R20: 19k; R_0805_2012Metric_Pad1.15x1.40mm_HandSolder
R21: 100; R_0805_2012Metric_Pad1.15x1.40mm_HandSolder
R22: 31k; R_0805_2012Metric_Pad1.15x1.40mm_HandSolder
R27: 2k5; R_0805_2012Metric_Pad1.15x1.40mm_HandSolder
TP12, TP13: TestPoint_2Pole; PinHeader_1x02_P2.54mm_Vertical
U3: MCP6D11; MSOP-8_3x3mm_P0.65mm

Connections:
+5VA: C40.1, R21.1, U3.3 (V+), U3.7 (/PD); also elsewhere on the board
/Sheet5FE333A0/DC_CM: R26.2, R28.2; also elsewhere on the board
/Sheet5FE3342E/In+: R19.2, R23.2; also elsewhere on the board
/Sheet5FE3342E/In-: R17.2, R25.2; also elsewhere on the board
GNDA: C37.2, C38.2, C39.2, C40.2, C41.2, R22.2, R27.1, U3.6 (V-); also elsewhere on the board
unnamed: C34.1, C35.2, L18.2, Q2.3 (C2), R15.2, TP12.2
unnamed: C34.2, C35.1, L17.1, Q2.6 (C1), R15.1, TP12.1
unnamed: C36.1, R16.1, R18.1, TP13.1, U3.4 (Out+)
unnamed: C36.2, R18.2, R24.1, TP13.2, U3.5 (Out-)
unnamed: C37.1, Q2.2 (B1), Q2.5 (B2), R20.2, R22.1
unnamed: C38.1, C39.1, L17.2, L18.1, R20.1, R21.2
unnamed: C41.1, R28.1, U3.2 (Vocm)
unnamed: Q2.1 (E1), R23.1
unnamed: Q2.4 (E2), R25.1
unnamed: R16.2, R17.1, U3.8 (+)
unnamed: R19.1, R24.2, U3.1 (-)
unnamed: R26.1, R27.2

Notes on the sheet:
Szimulált terhelés (ADC)

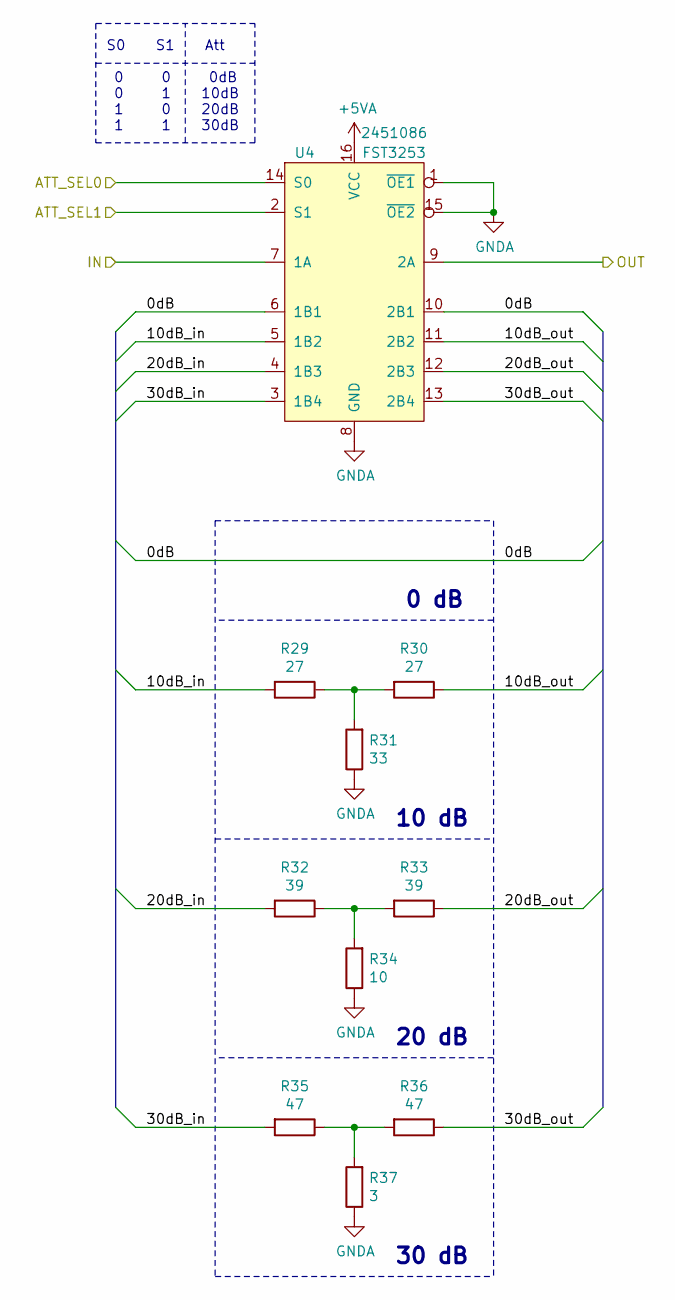
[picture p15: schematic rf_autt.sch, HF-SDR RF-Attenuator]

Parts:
R29, R30: 27; R_0805_2012Metric_Pad1.15x1.40mm_HandSolder
R31: 33; R_0805_2012Metric_Pad1.15x1.40mm_HandSolder
R32, R33: 39; R_0805_2012Metric_Pad1.15x1.40mm_HandSolder
R34: 10; R_0805_2012Metric_Pad1.15x1.40mm_HandSolder
R35, R36: 47; R_0805_2012Metric_Pad1.15x1.40mm_HandSolder
R37: 3; R_0805_2012Metric_Pad1.15x1.40mm_HandSolder
U4: FST3253; TSSOP-16_4.4x5mm_P0.65mm; Farnell 2451086

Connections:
+5VA: U4.16 (VCC); also elsewhere on the board
/Attenuator/0dB: U4.6 (1B1), U4.10 (2B1)
/Attenuator/10dB_in: R29.2, U4.5 (1B2)
/Attenuator/10dB_out: R30.1, U4.11 (2B2)
/Attenuator/20dB_in: R32.2, U4.4 (1B3)
/Attenuator/20dB_out: R33.1, U4.12 (2B3)
/Attenuator/30dB_in: R35.2, U4.3 (1B4)
/Attenuator/30dB_out: R36.1, U4.13 (2B4)
/Attenuator/ATT_SEL0: U4.14 (S0); also elsewhere on the board
/Attenuator/ATT_SEL1: U4.2 (S1); also elsewhere on the board
/Attenuator/IN: U4.7 (1A); also elsewhere on the board
/Attenuator/OUT: U4.9 (2A); also elsewhere on the board
GNDA: R31.1, R34.1, R37.1, U4.1 (~OE1), U4.8 (GND), U4.15 (~OE2); also elsewhere on the board
unnamed: R29.1, R30.2, R31.2
unnamed: R32.1, R33.2, R34.2
unnamed: R35.1, R36.2, R37.2

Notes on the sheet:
30 dB
20 dB
10 dB
0 dB
S0 S1 Att 0 0 0dB 0 1 10dB 1 0 20dB 1 1 30dB

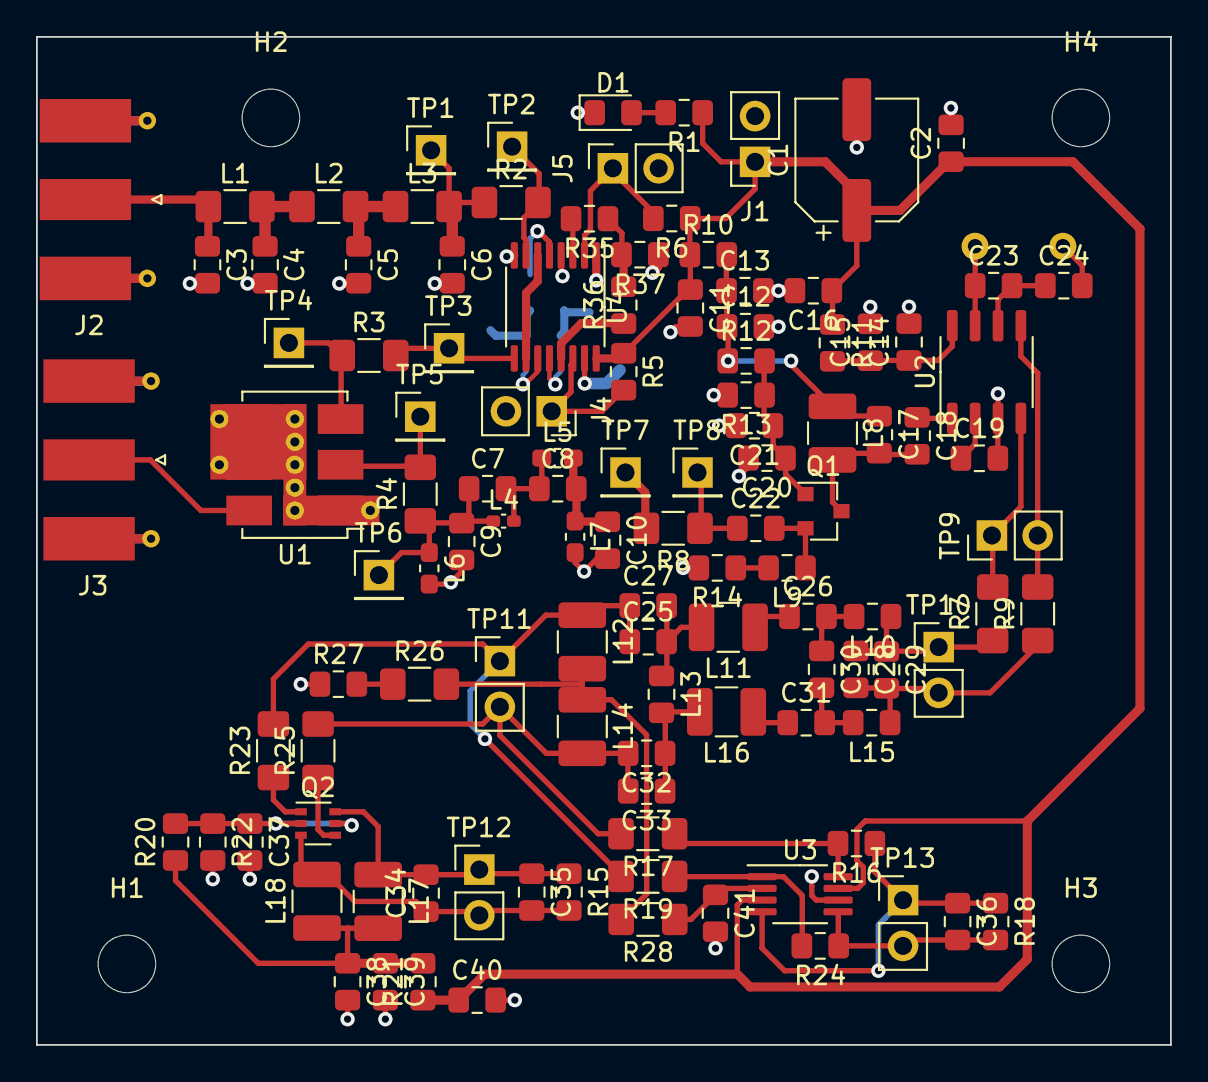
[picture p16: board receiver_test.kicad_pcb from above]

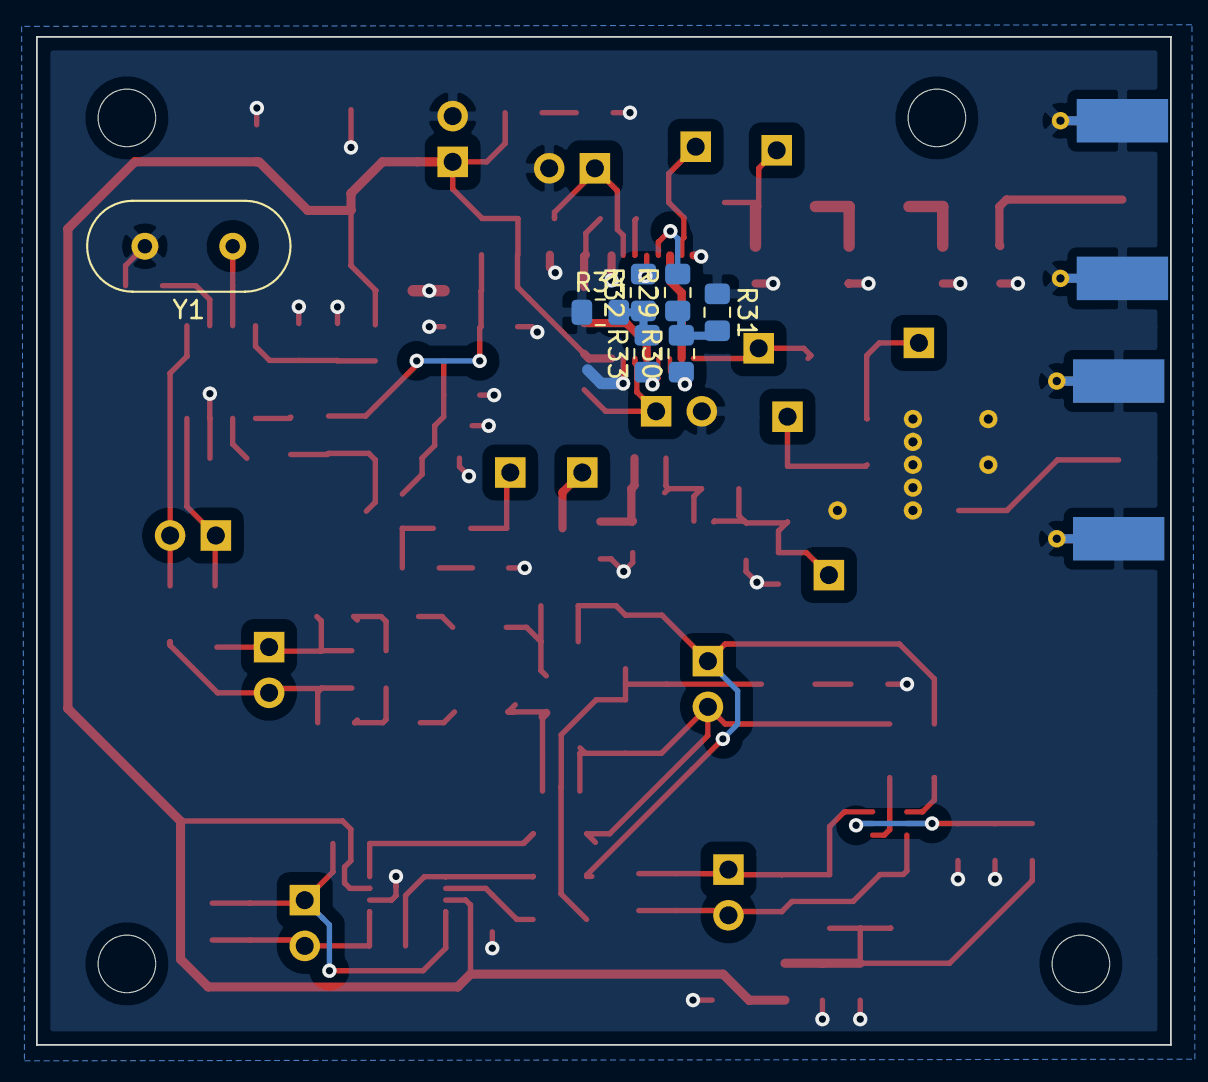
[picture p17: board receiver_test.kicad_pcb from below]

Board: 2 copper layers, 63.0 x 56.0 mm, 126 parts (7 on the bottom side), 64 nets.

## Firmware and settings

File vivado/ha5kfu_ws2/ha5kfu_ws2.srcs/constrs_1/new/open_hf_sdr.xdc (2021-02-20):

#DAC section
set_property IOSTANDARD LVCMOS33 [get_ports {dac_data[*]}]
set_property IOSTANDARD LVCMOS33 [get_ports {dac_clk}]
set_property SLEW SLOW [get_ports {dac_data[*]}]
set_property SLEW SLOW [get_ports {dac_clk}]
#set_property DRIVE 10 [get_ports {dac_data[*]}]
#set_property DRIVE 10 [get_ports {dac_clk}]

set_property IO_0_14 [get_ports {dac_data[0]}]
set_property IO_L1P_T0_D00_MOSI_14 [get_ports {dac_data[1]}]
set_property IO_L1N_T0_D01_DIN_14 [get_ports {dac_data[2]}]
set_property IO_L2P_T0_D02_14 [get_ports {dac_data[3]}]
set_property IO_L2N_T0_D03_14 [get_ports {dac_data[4]}]
set_property IO_L3P_T0_DQS_PUDC_B_14 [get_ports {dac_data[5]}]
set_property IO_L3N_T0_DQS_EMCCLK_14 [get_ports {dac_data[6]}]
set_property IO_L4P_T0_D04_14 [get_ports {dac_data[7]}]
set_property IO_L4N_T0_D05_14 [get_ports {dac_data[8]}]
set_property IO_L5P_T0_D06_14 [get_ports {dac_data[9]}]
set_property IO_L5N_T0_D07_14 [get_ports {dac_data[10]}]
set_property IO_L6P_T0_FCS_B_14 [get_ports {dac_data[11]}]
set_property IO_L6N_T0_D08_VREF_14 [get_ports {dac_data[12]}]
set_property IO_L7P_T1_D09_14 [get_ports {dac_data[13]}]
set_property IO_L7N_T1_D10_14 [get_ports {dac_clk}]

#Clock section
set_property IOSTANDARD LVCMOS33 [get_ports {input_clk}]

set_property IO_L8P_T1_D11_14 [get_ports {input_clk}]

#ADC section
set_property IOSTANDARD LVCMOS33 [get_ports {adc_clk}]
set_property IOSTANDARD LVCMOS33 [get_ports {adc_data[*]}]
set_property IOSTANDARD LVCMOS33 [get_ports {adc_power_down}]

set_property IO_L8N_T1_D12_14 [get_ports {adc_clk}]
set_property IO_L9P_T1_DQS_14 [get_ports {adc_data[0]}]
set_property IO_L9N_T1_DQS_D13_14 [get_ports {adc_data[1]}]
set_property IO_L10P_T1_D14_14 [get_ports {adc_data[2]}]
set_property IO_L10N_T1_D15_14 [get_ports {adc_data[3]}]
set_property IO_L11P_T1_SRCC_14 [get_ports {adc_data[4]}]
set_property IO_L11N_T1_SRCC_14 [get_ports {adc_data[5]}]
set_property IO_L12P_T1_MRCC_14 [get_ports {adc_data[6]}]
set_property IO_L12N_T1_MRCC_14 [get_ports {adc_data[7]}]
set_property IO_L13P_T2_MRCC_14 [get_ports {adc_power_down}]



#set_property IO_L13N_T2_MRCC_14 [get_ports {kimenet_xxx}]
#set_property IO_L14P_T2_SRCC_14 [get_ports {kimenet_xxx}]
#set_property IO_L14N_T2_SRCC_14 [get_ports {kimenet_xxx}]
#set_property IO_L15P_T2_DQS_RDWR_B_14 [get_ports {kimenet_xxx}]
#set_property IO_L15N_T2_DQS_DOUT_CSO_B_14 [get_ports {kimenet_xxx}]
#set_property IO_L16P_T2_CSI_B_14 [get_ports {kimenet_xxx}]
#set_property IO_L16N_T2_D31_14 [get_ports {kimenet_xxx}]
#set_property IO_L17P_T2_D30_14 [get_ports {kimenet_xxx}]
#set_property IO_L17N_T2_D29_14 [get_ports {kimenet_xxx}]
#set_property IO_L18P_T2_D28_14 [get_ports {kimenet_xxx}]
#set_property IO_L18N_T2_D27_14 [get_ports {kimenet_xxx}]
#set_property IO_L19P_T3_D26_14 [get_ports {kimenet_xxx}]
#set_property IO_L19N_T3_D25_VREF_14 [get_ports {kimenet_xxx}]
#set_property IO_L20P_T3_D24_14 [get_ports {kimenet_xxx}]
#set_property IO_L20N_T3_D23_14 [get_ports {kimenet_xxx}]
#set_property IO_L21P_T3_DQS_14 [get_ports {kimenet_xxx}]
#set_property IO_L21N_T3_DQS_D22_14 [get_ports {kimenet_xxx}]
#set_property IO_L22P_T3_D21_14 [get_ports {kimenet_xxx}]
#set_property IO_L22N_T3_D20_14 [get_ports {kimenet_xxx}]
#set_property IO_L23P_T3_D19_14 [get_ports {kimenet_xxx}]
#set_property IO_L23N_T3_D18_14 [get_ports {kimenet_xxx}]
#set_property IO_L24P_T3_D17_14 [get_ports {kimenet_xxx}]
#set_property IO_L24N_T3_D16_14 [get_ports {kimenet_xxx}]
#set_property IO_25_14 [get_ports {kimenet_xxx}]
#set_property IO_0_34 [get_ports {kimenet_xxx}]
#set_property IO_L1P_T0_34 [get_ports {kimenet_xxx}]
#set_property IO_L1N_T0_34 [get_ports {kimenet_xxx}]
#set_property IO_L2P_T0_34 [get_ports {kimenet_xxx}]
#set_property IO_L2N_T0_34 [get_ports {kimenet_xxx}]
#set_property IO_L3P_T0_DQS_34 [get_ports {kimenet_xxx}]
#set_property IO_L3N_T0_DQS_34 [get_ports {kimenet_xxx}]
#set_property IO_L4P_T0_34 [get_ports {kimenet_xxx}]
#set_property IO_L4N_T0_34 [get_ports {kimenet_xxx}]
#set_property IO_L5P_T0_34 [get_ports {kimenet_xxx}]
#set_property IO_L5N_T0_34 [get_ports {kimenet_xxx}]
#set_property IO_L6P_T0_34 [get_ports {kimenet_xxx}]
#set_property IO_L6N_T0_VREF_34 [get_ports {kimenet_xxx}]
#set_property IO_L7P_T1_34 [get_ports {kimenet_xxx}]
#set_property IO_L7N_T1_34 [get_ports {kimenet_xxx}]
#set_property IO_L8P_T1_34 [get_ports {kimenet_xxx}]
#set_property IO_L8N_T1_34 [get_ports {kimenet_xxx}]
#set_property IO_L9P_T1_DQS_34 [get_ports {kimenet_xxx}]
#set_property IO_L9N_T1_DQS_34 [get_ports {kimenet_xxx}]
#set_property IO_L10P_T1_34 [get_ports {kimenet_xxx}]
#set_property IO_L10N_T1_34 [get_ports {kimenet_xxx}]
#set_property IO_L11P_T1_SRCC_34 [get_ports {kimenet_xxx}]
#set_property IO_L11N_T1_SRCC_34 [get_ports {kimenet_xxx}]
#set_property IO_L12P_T1_MRCC_34 [get_ports {kimenet_xxx}]
#set_property IO_L12N_T1_MRCC_34 [get_ports {kimenet_xxx}]
#set_property IO_L13P_T2_MRCC_34 [get_ports {kimenet_xxx}]
#set_property IO_L13N_T2_MRCC_34 [get_ports {kimenet_xxx}]
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

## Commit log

2020-12-23 SDR receiver blocks
    [if1_amp.sch, if1_bpf.sch, if2_amp.sch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]
2020-12-23 RF filter implemented
    [if1_amp.sch, if1_bpf.sch, if2_amp.sch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]
2020-12-24 Attenuator revised
    [attenuator.sch, open-hf-sdr.kicad_pcb, open-hf-sdr.sch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]
2020-12-24 Second mixer
    [if1_amp.sch, if1_bpf.sch, if2_amp.sch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]
2020-12-26 Block diagram arrangement
    [sdr.sch]
2020-12-26 2nd IF amp test values
    [mixer2.sch, sdr.sch]
2020-12-27 IF1 BPF updated
    [if1_bpf.sch]
2020-12-28 if2_amp.sch
    if2_amp almost done
    [mixer2.sch, sdr.sch]
2020-12-28 if2_amp updated
    [if2_amp.sch]
2020-12-28 IF2 Filter Impedance Calculator
    [if2filtercalc.ods]
2020-12-28 if2 completed
    [if2_amp.sch, if2_bpf.sch, sdr.sch]
2020-12-29 IF2 amp discrete demo
    [if2_amp.sch]
2020-12-29 IF2 AMP modified collector tank
    [if2_amp.sch]
2020-12-30 If2 50 ohm filter
    [if2_amp.sch, if2_bpf.sch, sdr.sch]
2020-12-30 If2 filter ltspice file added
2020-12-31 CB diff amp LTSpice file added
    [if2filtercalc.ods]
2021-01-04 Tx initial commit
    [if1_bpf.sch, if2_amp.sch, if2_bpf.sch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]
2021-01-08 Fix grounding in rf autt
    [rf_autt.sch]
2021-01-08 Initalize receiver test circuit
    [if1_bpf.sch, if2_amp.sch, if2_bpf.sch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]
2021-01-09 Nyáktervezésre majdnem kész
    [if1_bpf.sch, if2_amp.sch, if2_bpf.sch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]
2021-01-15 Receiver test panel ++
    [if1_bpf.sch, if2_amp.sch, if2_bpf.sch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]
2021-01-15 IF2 filter and amp recalculate
    [if2_amp.sch, if2_bpf.sch]
2021-01-16 majdnem kész a nyák béta verziója
    [receiver_test.kicad_pcb]
2021-01-16 if2amp BP resistor added
    [if2_amp.sch]
2021-01-16 Add part number to auttenator
    [rf_autt.sch]
2021-01-16 FPGA added
    [fpga.sch, programmer.sch]
2021-01-16 if2_bpf revised + Schematic cleanup
    [if1_bpf.sch, if2_amp.sch, if2_bpf.sch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]
2021-01-16 Footprint reassociation, pcb clear
    [if1_bpf.sch, if2_amp.sch, mixer2.sch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]
2021-01-16 Pcb vHA8KDA
    [if2_amp.sch, if2_bpf.sch, mixer2.sch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]
2021-01-16 Pcb edges and spacer part number
    [if2_amp.sch, receiver_test.kicad_pcb, receiver_test.sch]
2021-01-17 IF1 modified to 37,224 MHz
    [if1_bpf.sch, mixer2.sch, receiver_test.sch]
2021-01-17 diffamp common mode fix
    [if2_amp.sch, receiver_test.kicad_pcb]
2021-01-17 FPGA change and new project file
    [fpga.sch, fpga_2.sch, if1_bpf.sch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]
2021-01-17 FPGA supply notes
    [fpga.sch, fpga_2.sch, if1_bpf.sch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]
2021-01-18 PCB is Done... Needs DRC check
    [if1_bpf.sch, if2_amp.sch, if2_bpf.sch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]
2021-01-18 RX PCB revision: Diff amp + Mixer2
    [if1_bpf.sch, if2_amp.sch, if2_bpf.sch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]
2021-01-18 Via stitching removed + Edge Cut resized
    [receiver_test.kicad_pcb]
2021-01-18 RX PCB gerbers exported
    [receiver_test-B_Cu.gbr, receiver_test-B_Mask.gbr, receiver_test-Edge_Cuts.gbr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]
2021-01-26 PSU init
    [if1_bpf.sch, if2_amp.sch, if2_bpf.sch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]
2021-01-30 Nézd meg!
    [receiver_test_final.kicad_pcb]
2021-01-31 Power supplies
    [if2_amp.sch, power_supply.sch, tx_filter.sch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]
2021-02-20 finish up power supply
    [if1_bpf.sch, mixer2.sch, power_supply.sch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]
2021-02-26 update buck converter diodes
    [power_supply.sch]
2021-02-26 add power on sequencing for fpga
    [fpga.sch, fpga_2.sch, fpga_int_aux_psu.sch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]
2021-02-26 one less transistor is enough
    [power_supply.sch]
2021-04-24 SDR-FPGA Interface v0
    [fpga.sch, if2_amp.sch, open_hf_sdr.sch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]
2021-04-24 Add notes to sdr.sch
    [sdr.sch]
2021-04-29 Begin the implementation of Human in-out, a few small changes
    [fpga.sch, fpga_2.sch, fpga_int_aux_psu.sch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]
2021-05-10 add more buttons
    [human_in_out.sch]
2021-05-10 Progress in programmer sheet
    [fpga.sch, fpga_2.sch, fpga_int_aux_psu.sch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]
2021-05-11 Add USB-FPGA bus labels
    [open_hf_sdr.sch, programmer.sch]
2021-05-11 Finish LED branches on programmer sheet
    [human_in_out.sch, programmer.sch]
2021-05-12 connect leds to fpga
    [fpga_2.sch, human_in_out.sch, open_hf_sdr.sch]
2021-05-12 Add USB connector
    [programmer.sch]
2021-05-12 plus 2 leds
    [fpga_2.sch, human_in_out.sch]
2021-05-12 Add oscillator
    [fpga.sch]
2021-05-12 Fix power pins
    [programmer.sch]
2021-05-12 Add unconnected marks
    [programmer.sch]
2021-05-12 Connect USB buses to the FPGA
    [fpga.sch, fpga_2.sch, open_hf_sdr.sch]
2021-05-12 Add LED15 and LED16
    [fpga_2.sch, human_in_out.sch]
2021-05-12 Power supply ,,typo" fixes
    [fpga_int_aux_psu.sch, power_supply.sch]
2021-05-14 Center main sheet
    [open_hf_sdr.sch]
2021-05-14 Power suppley fixes
    [fpga_int_aux_psu.sch, power_supply.sch, psu_main_buck.sch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]
2021-05-14 Add battery monitoring, and reverse polarity check
    [open_hf_sdr.sch, power_supply.sch]
2021-05-14 Battery overdischarge jumper changed
    [power_supply.sch]
2021-05-18 fix battery protection jumper
    [power_supply.sch, psu_main_buck.sch]
